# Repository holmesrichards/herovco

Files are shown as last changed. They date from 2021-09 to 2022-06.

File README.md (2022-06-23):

# Hero VCO

The Hero VCO is a 3340 based voltage controlled oscillator synth module in Kosmo format. Notable features of the Hero include:

* Triangle, ramp, pulse, and sine waveforms with separate output jacks.
* Uniform, zero-centered ±5 Vpp output amplitudes for the various wave shapes.
* Input jacks for two V/oct CVs, as well as PWM, linear FM, and exponential FM (pitch) CVs with attenuators.
* Separate initial pulse width and PWM attenuator knobs.
* Wide pulse width range.
* Switch selectable hard, soft, or no sync.
* 11 position octave switch plus fine tuning knob.
* Front panel access to trimmers for calibration of V/oct tracking, center pitch, and pulse width range limit.
* Entirely through hole construction with readily available components.

Two well known problems with the 3340 in its datasheet configuration are addressed:

* Regulated -5 V supply improves stability and suppresses pulse width frequency shift.
* Falling edge oscillations on pulse wave shape are eliminated.

But perhaps the most significant feature of the design is the link header. This may be used to connect the Hero to one or more of its sister module, the [Sidekick VCO](https://github.com/holmesrichards/sidekickvco), in a modern riff on the classic Moog 921a/921b system. The Sidekick is half the width of the Hero and lacks some of the Hero's front panel controls and inputs, but internally is essentially the same circuit as the Hero. Via the link, the Sidekicks receive summed V/oct pitch CV, linear FM CV, and pulse width CV from the Hero, based on its front panel controls and inputs. In this way a common set of control voltages is presented to the Hero and all its Sidekicks. The link also permits the Sidekicks to be hard or soft synced to the Hero. This allows easy configuration of a multi-oscillator synth voice in a relatively compact system.

The Hero design specifies and assumes the Alfa AS3340A VCO chip, an improvement to the AS3340, although the AS3340 or Curtis CEM3340 probably would work. (See build notes.)

Thanks for inspiration to several other VCOs: the [Kassutronics VCO 3340](https://kassu2000.blogspot.com/2018/06/vco-3340.html), the [LMNC 1222 Performance VCO](https://www.lookmumnocomputer.com/1222-performance-vco), and the [Thomas Henry VCO Maximus](https://www.birthofasynth.com/Thomas_Henry/Pages/VCO_Maximus-Detail.html).

## Project status

One prototype (v. 0.91) has been built and it works. There were some minor issues identified:

- L79L05 footprint does not have wide leg spacing.
- Jack footprints are round holes instead of slots.
- 330pF cap footprint is 2.5 mm pitch, should be 5 mm.
- Resistors specified for octave switch are 100k, 10k would be (arguably) better.
- No indication on silkscreen for which resistors to match.
- Some silkscreen refs obscured by pads.
- Resistors between trimmers make assembly awkward, move to other side of board.
- Slide switch footprint incorrect, requires cutting off mounting legs.

See build notes for mitigations. These issues have been corrected in the design files but the revised version has not been tested. 

## Width

10 cm.

## Current draw
33 mA +12 V, 34 mA -12 V.

## Photos

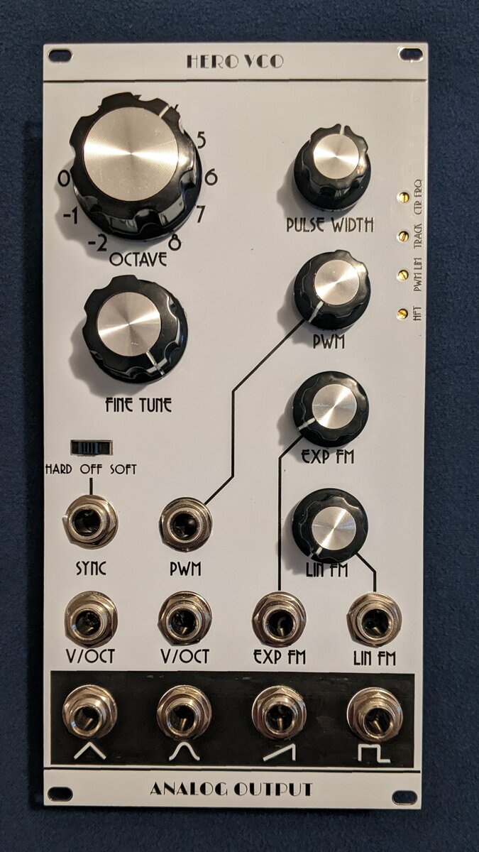
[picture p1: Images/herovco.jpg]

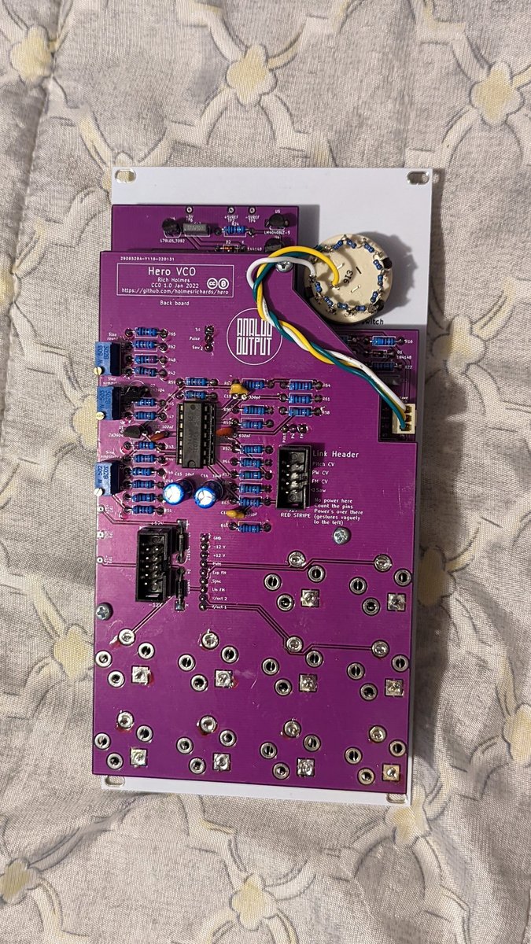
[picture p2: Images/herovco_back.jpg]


## Documentation

* [Schematic](Docs/herovco.pdf)
* PCB layout: [front](Docs/herovco_layout_front.pdf), [back](Docs/herovco_layout_back.pdf)
* [BOM](Docs/herovco_bom.md)
* [Build notes](Docs/build.md)
* [How it works](Docs/howitworks.md)
* [Blog post](https://analogoutputblog.wordpress.com/2022/06/20/hero-and-sidekick/)

## GitHub repository

* [https://github.com/holmesrichards/herovco](https://github.com/holmesrichards/herovco)

## Submodules

This repo uses submodules aoKicad and Kosmo_panel, which provide needed libaries for KiCad. To clone:

```
git clone git@github.com:holmesrichards/herovco.git
git submodule init
git submodule update
```

Alternatively do

```
git clone --recurse-submodules git@github.com:holmesrichards/herovco.git
```

Or if you download the repository as a zip file, you must also click on the "aoKicad" and "Kosmo\_panel" links on the GitHub page (they'll have "@ something" after them) and download them as separate zip files which you can unzip into this repo's aoKicad and Kosmo\_panel directories.

If desired, copy the files from aoKicad and Kosmo\_panel to wherever you prefer (your KiCad user library directory, for instance, if you have one). Then in KiCad, go into Edit Symbols and add symbol libraries 

```
aoKicad/ao_symbols
Kosmo_panel/Kosmo
```
and go into Edit Footprints and add footprint libraries 
```
aoKicad/ao_tht
Kosmo_panel/Kosmo_panel.
```

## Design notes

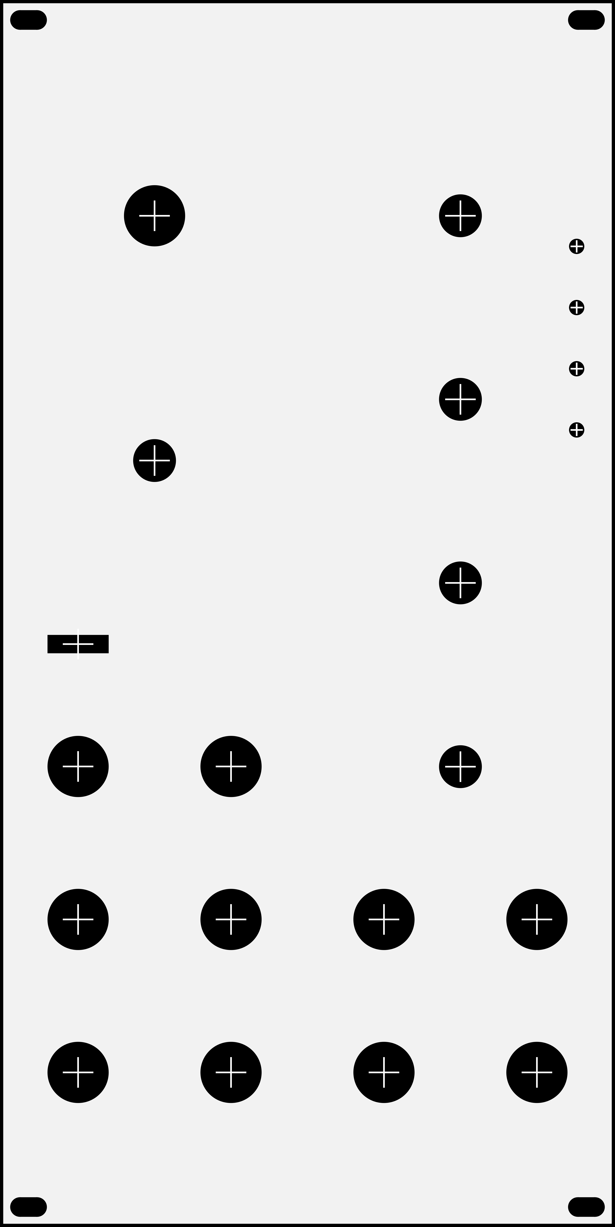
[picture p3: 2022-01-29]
Images/herovco_panel_holes.png

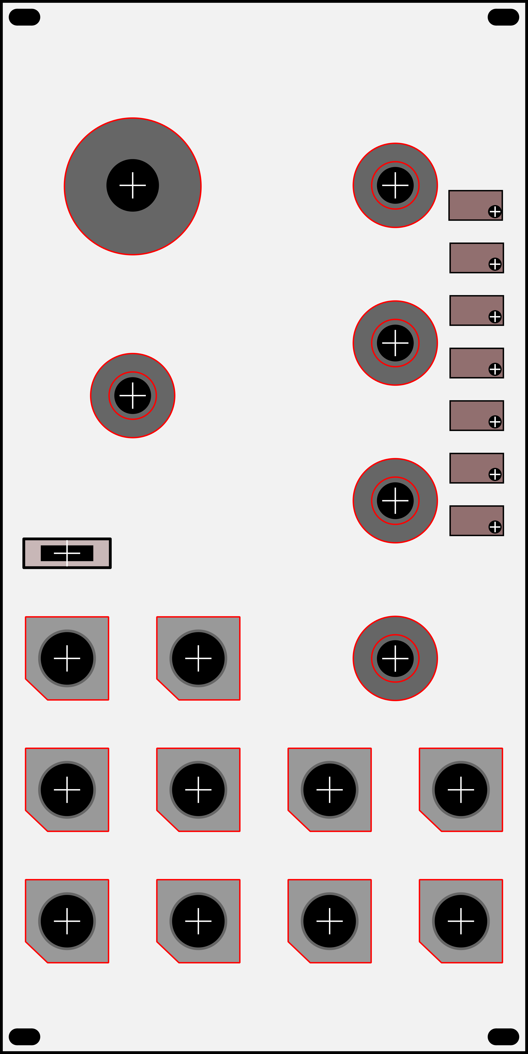
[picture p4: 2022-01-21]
Images/herovco_panel_behind.png

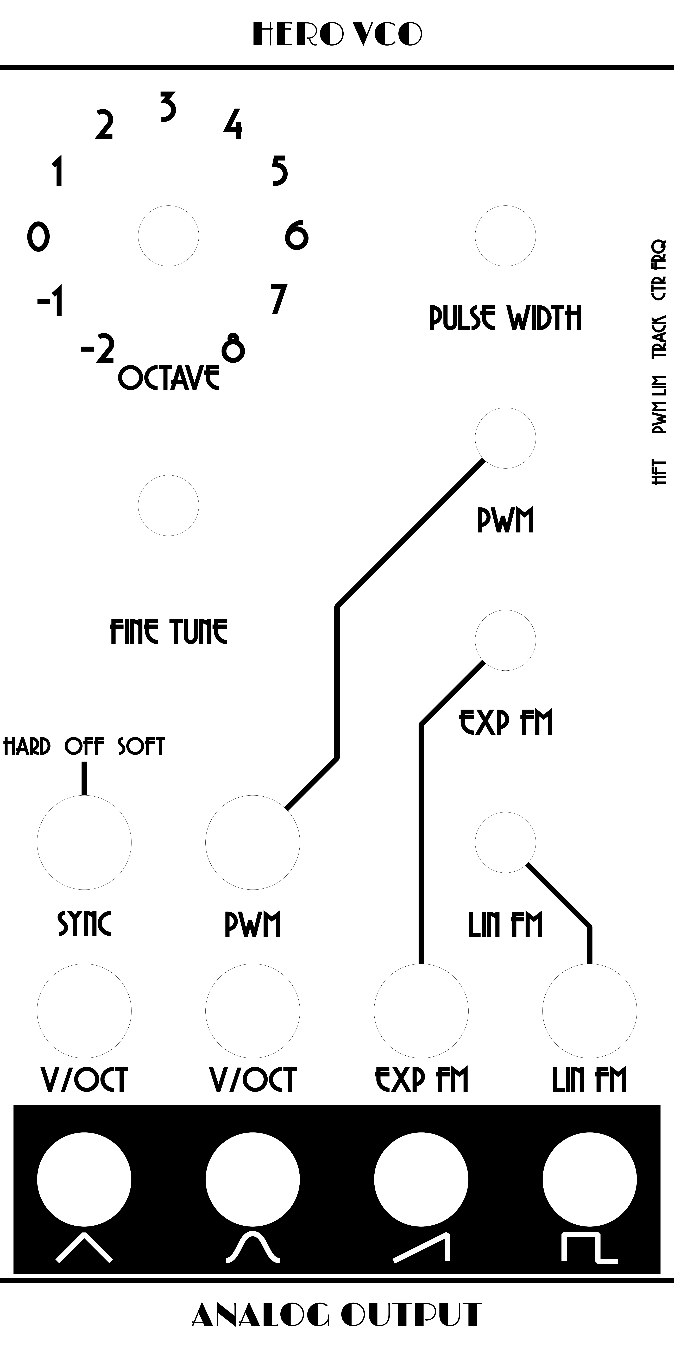
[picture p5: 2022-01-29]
Images/herovco_panel_art.png

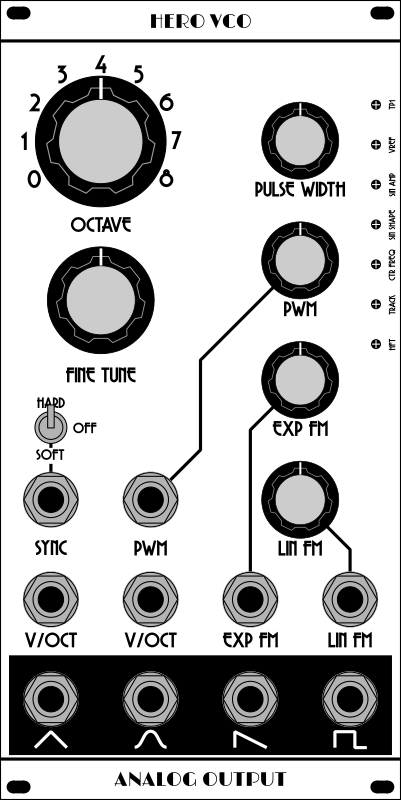
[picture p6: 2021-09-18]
Images/herovco_panel.png

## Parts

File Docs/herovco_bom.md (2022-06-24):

# herovco.kicad_sch BOM

Sun 19 Jun 2022 12:42:01 PM EDT

Generated from schematic by Eeschema 6.0.5-a6ca702e91~116~ubuntu20.04.1

**Component Count:** 133

| Refs | Qty | Component | Description | Manufacturer | Part | Vendor | SKU |
| ----- | --- | ---- | --- | ---- | ---- | ---- | ---- |
| C1, C2, C3, C4, C5, C6, C16, C17 | 8 | 100nF | Ceramic capacitor, pitch 2.5 mm |  |  | Tayda |  |
| C7, C12 | 2 | 100nF | Film capacitor, pitch 5 mm |  |  | Tayda | A-564 |
| C8, C10, C11, C13 | 4 | 10nF | Film capacitor, pitch 5 mm |  |  | Tayda | A-559 |
| C9 | 1 | 1nF | Polypropylene film capacitor |  |  | Digi-Key | FKP2G011001D00HSSD |
| C14, C15 | 2 | 10uF | Electrolytic capacitor, pitch 2.5 mm |  |  | Tayda |  |
| C18, C19 | 2 | 330pF | Ceramic capacitor, pitch 5 mm |  |  | Tayda |  |
| D1, D2 | 2 | 1N4148 | Standard switching diode, DO-35 |  |  | Tayda | A-157 |
| D3, D4 | 2 | 1N5817 | Schottky Barrier Rectifier Diode, DO-41 |  |  | Tayda | A-159 |
| J1 | 1 | Conn_01x09 | 1x9 pin header, pitch 2.54 mm |  |  |  |  |
| J2, J3 | 2 | Conn_01x03 | 1x3 pin header, pitch 2.54 mm |  |  |  |  |
| J4 | 1 | 3_pin_Molex_header | KK254 Molex header |  |  | Tayda | A-805 |
| J9 | 1 | Conn_01x09 | 1x9 pin socket, pitch 2.54 mm |  |  |  |  |
| J10, J11 | 2 | Conn_01x03 | 1x3 pin socket, pitch 2.54 mm |  |  |  |  |
| J12 | 1 | 3_pin_Molex_connector | KK254 Molex connector |  |  | Tayda | A-827 |
| J17 | 1 | Conn_02x04_Odd_Even | 2x4 shrouded pin header, pitch 2.54 mm |  |  | Tayda | A-2948 |
| J18, J19, J20, J21, J22, J24, J25, J26, J27, J28 | 10 | AudioJack2 | 1/4" audio jack, vertical |  |  | Tayda | A-1121 |
| J23 | 1 | Synth_power_2x5 | 2x5 shrouded pin header, pitch 2.54 mm |  |  | Tayda | A-2939 |
| Q1, Q2 | 2 | 2N3904 | Small Signal NPN Transistor, TO-92 |  |  | Tayda | A-111 |
| R1, R18, R19 | 3 | 1M | Resistor |  |  | Tayda |  |
| R2, R56, R57, R58 | 4 | 24k | Resistor |  |  | Tayda |  |
| R3, R16 | 2 | 5.6k | Resistor |  |  | Tayda |  |
| R4, R5, R6, R8, R10, R21, R26, R28 | 8 | 100k | Resistor |  |  | Tayda |  |
| R7 | 1 | 470k | Resistor |  |  | Tayda |  |
| R9, R12, R22, R27, R31, R44, R46, R62, R63, R64 | 10 | 10k | Resistor |  |  | Tayda |  |
| R11, R15 | 2 | 470R | Resistor |  |  | Tayda |  |
| R13 | 1 | 1.8k | Resistor |  |  | Tayda |  |
| R14 | 1 | 1.5M | Resistor |  |  | Tayda |  |
| R17, R20, R29 | 3 | 47k | Resistor |  |  | Tayda |  |
| R23, R24, R65, R66, R67 | 5 | 1k | Resistor |  |  | Tayda |  |
| R25 | 1 | 240k | Resistor |  |  | Tayda |  |
| R30, R49, R50 | 3 | 20k | Resistor |  |  | Tayda |  |
| R32, R33, R34, R35, R36, R37, R38, R39, R40, R41 | 10 | 10k 1/8W | Resistor |  |  | Tayda |  |
| R42 | 1 | 30k | Resistor |  |  | Tayda |  |
| R43, R48 | 2 | 2.2k | Resistor |  |  | Tayda |  |
| R45 | 1 | 390R | Resistor |  |  | Tayda |  |
| R47, R52, R54, R55 | 4 | 18k | Resistor |  |  | Tayda |  |
| R51 | 1 | 2k | Resistor |  |  | Tayda |  |
| R53 | 1 | 33k | Resistor |  |  | Tayda |  |
| R59, R60, R61 | 3 | 9.1k | Resistor |  |  | Tayda |  |
| RV1, RV3, RV4, RV7, RV8 | 5 | 100k | Board mount linear potentiometer |  |  | Tayda | A-1848 or A-5513 |
| RV2, RV5, RV6 | 3 | 10k | 3296W trimmer potentiometer |  |  | Tayda | A-586 |
| RV9, RV10, RV11 | 3 | 50k | 3296W trimmer potentiometer |  |  | Tayda | A-598 |
| RV12 | 1 | 5k | 3296W trimmer potentiometer |  |  | Tayda | A-597 |
| SW1 | 1 | SW_Rotary12 | rotary switch with 12 positions |  |  | Tayda | A-1893 |
| SW2 | 1 | SW_DP3T | Switch, three position, dual pole triple throw, 3 position switch, SP3T | C&K | OS203012MU5QP1‎ | Digi-Key | CKN9554-ND |
| U1, U7 | 2 | TL074 | Quad operational amplifier, DIP-14 |  |  | Tayda | A-1138 |
| U2 | 1 | TL072 | Dual operational amplifier, DIP-8 |  |  | Tayda | A-037 |
| U3 | 1 | AS3340A | VCO |  |  | CabinTech Global |  |
| U4, U5 | 2 | LM4040BIZ-5 | 5.000V Precision Micropower Shunt Voltage Reference, TO-92 |  |  | Digi-Key | LM4040BIZ-5/NOPB-ND |
| U6 | 1 | L79L05_TO92 | Negative 100mA -30V Linear Regulator, Fixed Output -5V, TO-92 |  |  | Tayda | A-4676 |
| | 6 | | Knob | | | | |
| | 1 | | 8 pin DIP socket | | | Tayda | A-001 |
| | 2 | | 14 pin DIP socket | | | Tayda | A-004 |
| | 1 | | 16 pin DIP socket | | | Tayda | A-003 |

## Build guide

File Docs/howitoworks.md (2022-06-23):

# How the Hero VCO works

## Control voltages

RV4 and U1D attenuate and buffer the linear FM control voltage. It is AC coupled by C10, then R18 converts the voltage to current for input to the 3340 chip. The buffered CV is also sent to the link header.

The octave switch voltage output is buffered by U1A. The exponential CV is attenuated by RV3. RV1 supplies an adjustable offset voltage for fine tuning. All of these together with the two V/oct CVs are summed and inverted via R4 through R8, U1B, and R10, then re-inverted by R9, R12, and U1C, all with unity gain. To make sure the octave switch and V/oct CVs remain accurately 1 V/oct the gains of both stages must be accurately unity, so the relevant input and feedback resistors must be matched. The output of U1C goes to the link header, and to summing resistor R21. RV5 attenuates the high frequency tracking voltage from the 3340, and RV6 creates an adjustable offset voltage to set the center frequency. They also go to summing resistors and from there to the 3340 CV node.

The sync input is sent via switch SW2 to either the hard or soft sync circuit, or neither. For hard sync the level is divided by R15 and R22, the pulse width is set by those in combination with C7, and D1 causes only negative going pulses to be sent. For soft sync, R17 combined with C7 establishes the pulse width. If neither is selected, C12 is connected to the soft sync pin as recommended in the 3340 datasheet.

The pulse width modulation CV is attenuated by RV8, and RV7 supplies an adjustable pulse width voltage; these are summed and inverted with suitable gains by R25, R26, R28, and U2A. R29, R30, and RV9 scale and offset the resulting voltage to correspond to the 3340's PWM range (about 0 to 4 V with 12 V supply). R27, R31, and U2B re-invert the sum to be sent to the link header.

## 3340

The 3340 connections are mostly as in the datasheet. VEE is connected directly to -5 V, rather than via a resistor to -12 V, to improve performance and eliminate the pulse width frequency shift. R1 between pins 4 and 5 eliminates ringing oscillations on the falling edge of the pulse waveform.

## ±5 V references

Two LM4040 shunt voltage references, U4 and U5, are used with current limiting resistors R23 and R24 to create accurate ±5 V references, used by the fine tune control, center frequency trimmer, and octave switch.

## -5 V regulator

U6 is a voltage regulator to supply negative power to the 3340. D2 and C13 are per the L79L05 datasheet.

## Octave switch

Matched 10k resistors form a precision voltage divider between ±5 V whose output is +5, +4, +3, ... -4, -5 V. 

## Output conditioning

The 3340's waveform outputs are about 0 to 10.5 V for pulse, 0 to 8 V for ramp/saw, and 0 to 4 V for triangle. The triangle waveform is rescaled and offset to ±5 V by R56, R59, R62, and U7C. R56 and R59 divide +12 V down to the desired offset and the ratio of R62 to these resistors sets the gain. R65 limits current to the waveform output jack. 

The same rescaling and offset circuit is used on the ramp and pulse waveforms as well, after a voltage divider (R52 and R54 for ramp, R53 and R55 for pulse) scales these outputs down to 0 to 4 V. R53 and R55 also serve as a 51k pulldown as called for in the AS3340 datasheet.

Using the +12 V rail for the offset means it is sensitive to power supply fluctuations, but this is not likely to be a concern.

## Sine shaping

The sine shaping circuit is based on a differential transistor pair, Q1 and Q2. This is a standard tri to sine design. The amount of rounding depends on the input signal level so attenuator RV10 gives control over that. RV11 adjusts the balance between the two transistors' bias to control the symmetry of the rounding. U7D with R49 and R50 is a differential current amplifier, turning the difference in the collector currents into an output voltage. R51 and RV12 attenuate the output down to ±5 V.

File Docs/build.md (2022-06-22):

# Hero VCO build notes

## v0.91 issues

The first PCB run (v0.91) had some minor issues, easily worked around:

- L79L05 footprint does not have wide leg spacing. The irony is that of the five TO-92 devices in the VCO, this was for me the only one whose legs were wide spread as supplied. They had to be bent back inward. (And the legs on the other four I bent outward.)
- 330pF cap footprint is 2.5 mm pitch. The caps I had were 5 mm pitch. Again, I bent the legs inward.
- Slide switch footprint is incorrect. Electrically it is fine but the two holes for the mounting pins are placed wrong. I just cut the mounting pins off the switch and relied on the terminals to hold it in place.
- Resistors R2, R19, R20, and R30, located between the trimmer footprints on the front board on the same side as the other non-pot components, make it a little awkward to solder those trimmers later. You can move those resistors to the other side of the PCB to solve that. (In later versions the silkscreen shows these on the pots side of the board.)

## Which chip

The design specifies and assumes the Alfa AS3340A VCO chip, an improvement to the AS3340, although the AS3340 or Curtis CEM3340 probably would work. I have not tested either extensively. The CEM datasheet says the pulse output should have a 10k pulldown, versus 51k for the AS3340(A), though reportedly anything in that range works acceptably for either (see Sam Battle's LMNC 1222 schematic). If using CEM and you want to stick to the datasheet you could try changing R53 from 33k to 6.2k and R55 from 18k to 3.6k.

## Resistor matching

For proper V/oct tuning, certain groups of resistors need to be matched to one another to high precision. You can buy 0.1% precision resistors, but it is much cheaper to buy 100 or so 1% resistors and then measure them, setting aside ones that match at the 0.1% level. The actual value of the resistance is not critical, only that it be the same for resistors in each group. Different groups do not need to match each other.

Resistor groups to be matched are:

* Summing and feedback resistors in pitch CV input stage: R4, R5, R6, and R10 (100k). Note the resistors after the fine tune and CV in knobs do not need to be matched.
* Summing and feedback resistors in inverter stage: R9, R12 (10k).
* Octave switch resistors: R32 through R41 (10k).

*It would not hurt to make a note of the resistance values for each group.* You will want to know this if you ever need to replace one of these resistors.

## Octave switch

Resistors R32 through R41 are not mounted on the PCB; they are soldered directly to the octave switch: R41 from pin 1 to pin 2, R40 from pin 2 to pin 3, and so on up through R32 from pin 10 to pin 11. (Nothing is connected to pin 12.) These resistors are specified as 1/8 W metal film, solely because they fit nicely between the switch pins. You can use 1/4 watt resistors if that is what you have. They're just more awkward to place.

Three wires are connected to a Molex connector, to attach to header J4 on the circuit board. The wire connecting to the header pin marked +5V connects to rotary switch pin 11. The wire to header pin -5V connects to pin 1. The wire to header pin Octave connects to the center pin.

## Mechanical assembly

As usual, components that are mounted to or aligned with holes in the front panel should be put in place on the PCB without soldering, then the panel should be put on, then the parts should be soldered.

With the parts I used, the combined heights of the pin headers and sockets was going to be a couple mm short of the spacing between the PCBs. To reduce that discrepancy I put a couple of washers on each pot shaft underneath the front panel. There still is a gap between the pin header and socket housings but it's smaller and they make good electrical contact.

### Slide switch daughterboard
With those washers in place I did the following:

* I soldered the slide switch to its daughterboard. See note above about erroneous footprint in version v0.91. Switch goes on the side with the footprint on the silkscreen.
* With the daughterboard switch side down, I put a piece of solid wire (resistor leg cutoffs) in each of the four corner holes and soldered them. I clipped them off on the switch side.
* I fed the four wires through the holes in the PCB, making sure the labels on the daughterboard matched those on the PCB.
* I put the front panel on, securing it to the pots with nuts.
* I turned the assembly panel side down, propping up the ends off the work surface, and made sure the switch actuator was going through its hole with the switch housing flush against the back of the panel.
* I soldered the four wires to the PCB and clipped off the excess.

Again, do that with the washers in place on the pot shafts!

## Calibration
The main calibration is the usual procedure with 3340 based oscillators:

* With the octave swich in position 3 adjust the Center freq trimmer to get a fairly low frequency (100 Hz or so)
* Use a calibrated V/oct source such as a CV keyboard or MIDI/CV module to send 0 V and 2 V alternately to the V/oct input. Adjust the Tracking trimmer until the frequency ratio at these two CV values equals 2.000 ± 0.002.
* Turn the octave switch up to position 6. Again alternating 0 V and 2 V on the V/oct input, adjust the Hi freq track trimmer until the frequency ratio at these two CV values equals 2.000 ± 0.002.
* Repeat the last two steps if necessary to get the tracking as accurate as you can.
* Re-adjust the center frequency trimmer to your liking. I set it so with no CV inputs, the octave switch on 4, and the fine tuning knob centered, the pitch was C4 (262 Hz).

(I did the calibration using my new MI Module Tester and it made it so easy it was ridiculous!)

There are still four more trimmers! One is for the PWM upper limit. With no PWM CV, adjust it so when you turn the Pulse width knob up the pulse waveform either never gets so wide it stops, or gets just barely to the stopping point, as you prefer.

The other three trimmers are for the sine waveform. Put the sine waveform on a scope and adjust Sine symmetry to make the top and bottom of the waveform the same; adjust Sine round to make it a good sine shape. Once you're happy with those, adjust Sine amplitude to make the waveform 10 V peak to peak.

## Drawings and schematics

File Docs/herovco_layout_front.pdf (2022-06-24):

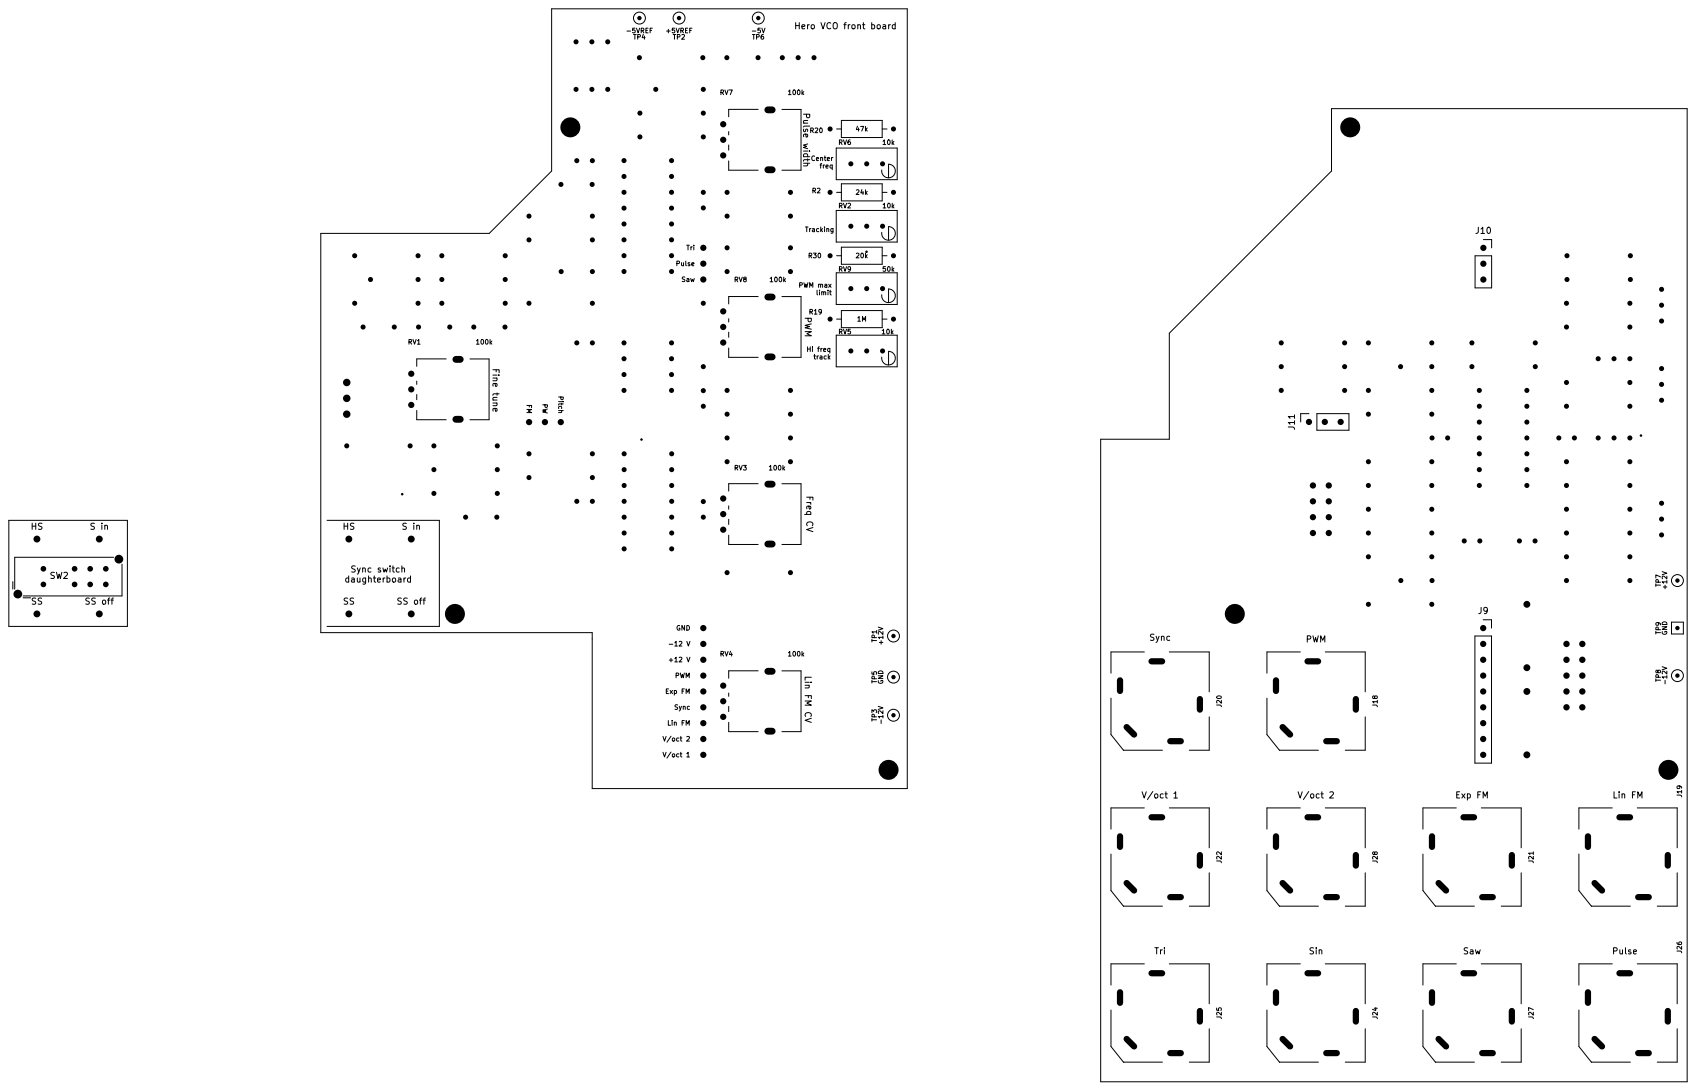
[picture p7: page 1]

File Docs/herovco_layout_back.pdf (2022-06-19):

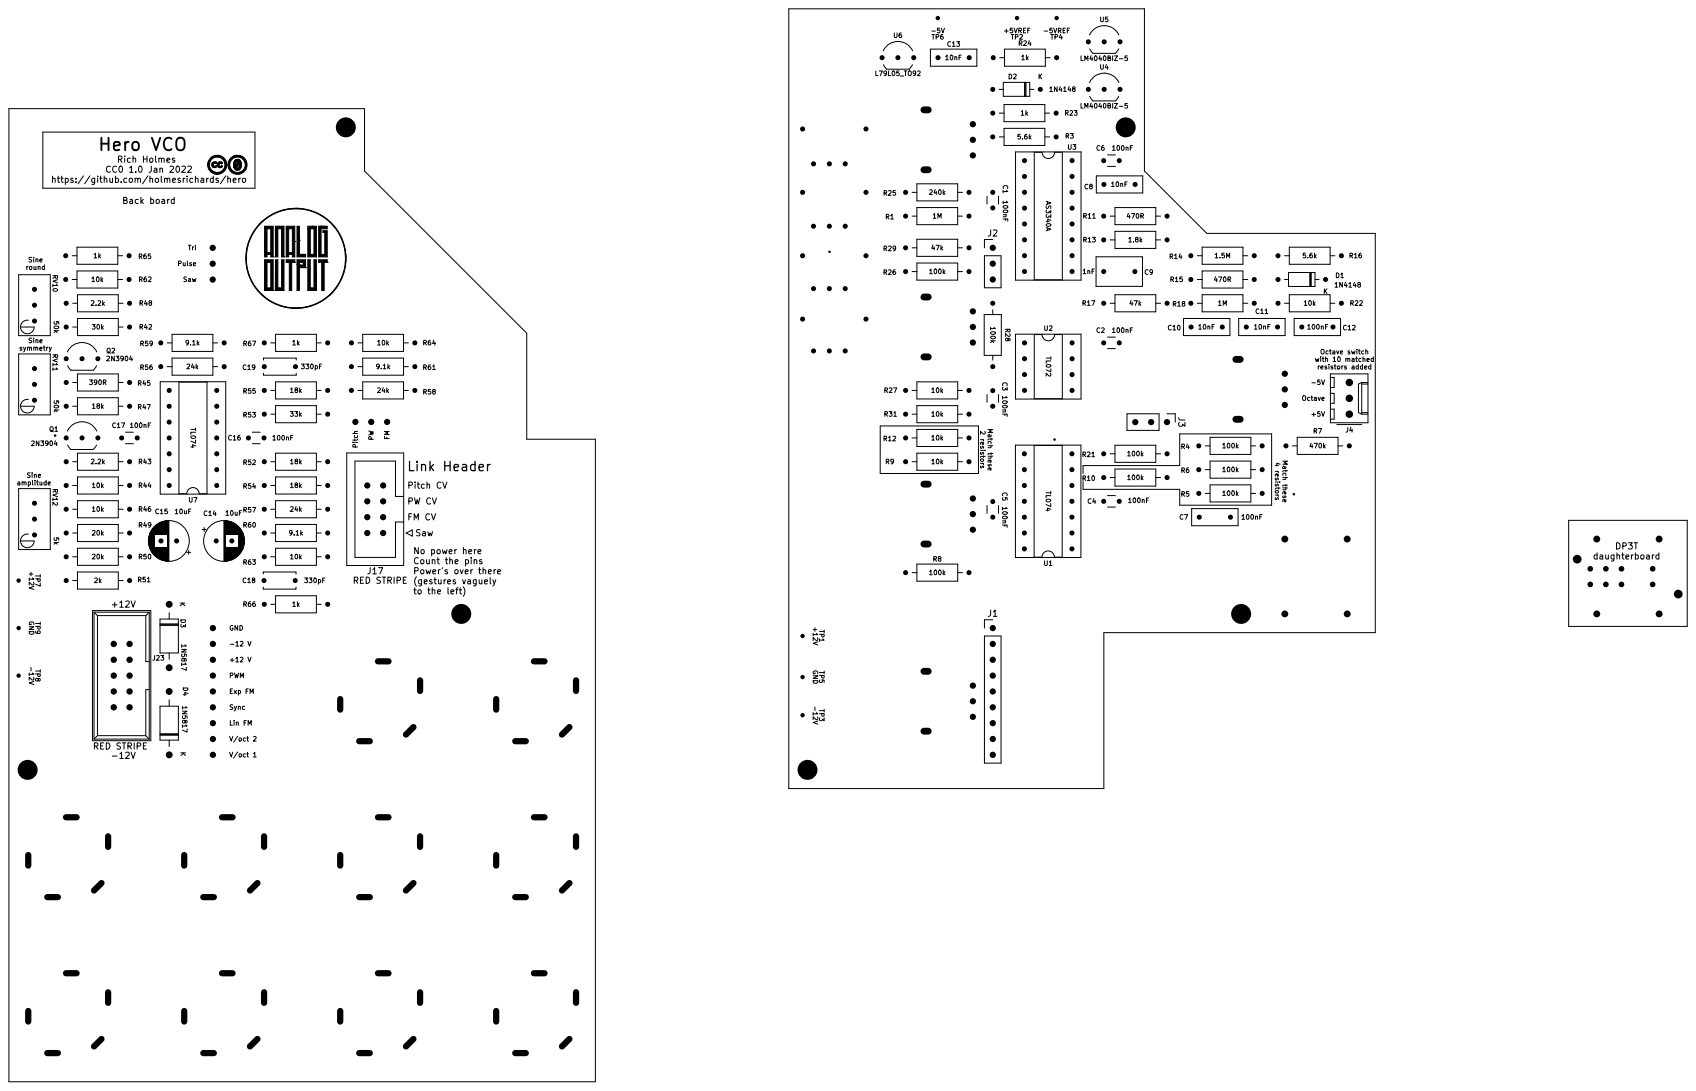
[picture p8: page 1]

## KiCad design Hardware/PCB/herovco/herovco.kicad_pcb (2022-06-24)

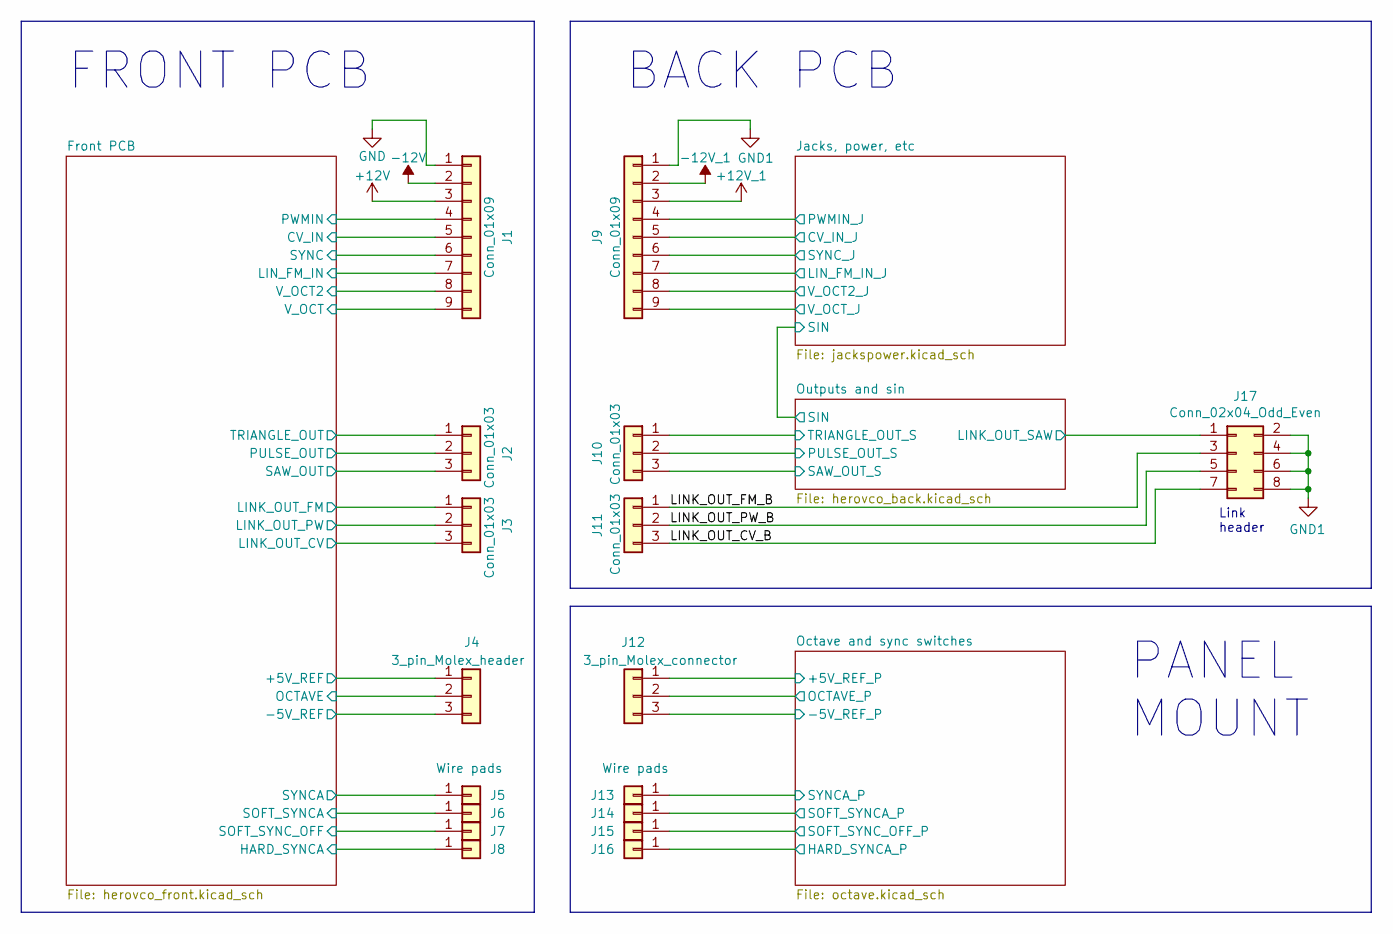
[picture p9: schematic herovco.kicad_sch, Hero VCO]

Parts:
J1: Conn_01x09; PinHeader_1x09_P2.54mm_Vertical
J2, J3: Conn_01x03; PinHeader_1x03_P2.54mm_Vertical
J4: 3_pin_Molex_header; Molex_KK-254_AE-6410-03A_1x03_P2.54mm_Vertical
J5, J13: Wire pads; SolderWire-0.5sqmm_1x01_D0.9mm_OD2.1mm
J6, J7, J8, J14, J15, J16: Conn_01x01; SolderWire-round_1x01_D0.9mm_OD2.1mm
J9: Conn_01x09; PinSocket_1x09_P2.54mm_Vertical
J10, J11: Conn_01x03; PinSocket_1x03_P2.54mm_Vertical
J12: 3_pin_Molex_connector; Molex_KK-254_AE-6410-03A_1x03_P2.54mm_Vertical
J17: Conn_02x04_Odd_Even; IDC-Header_2x04_P2.54mm_Vertical

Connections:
+12V: J1.3; also elsewhere on the board
+12V_1: J9.3; also elsewhere on the board
-12V: J1.2; also elsewhere on the board
-12V_1: J9.2; also elsewhere on the board
/Front PCB/+5V_REF: J4.1; also elsewhere on the board
/Front PCB/-5V_REF: J4.3; also elsewhere on the board
/Front PCB/CV_IN: J1.5; also elsewhere on the board
/Front PCB/CV_SUM: J3.3; also elsewhere on the board
/Front PCB/HARD_SYNCA: J8.1; also elsewhere on the board
/Front PCB/LINK_OUT_FM: J3.1; also elsewhere on the board
/Front PCB/LINK_OUT_PW: J3.2; also elsewhere on the board
/Front PCB/LIN_FM_IN: J1.7; also elsewhere on the board
/Front PCB/OCTAVE: J4.2; also elsewhere on the board
/Front PCB/PULSE_OUT: J2.2; also elsewhere on the board
/Front PCB/PWMIN: J1.4; also elsewhere on the board
/Front PCB/SAW_OUT: J2.3; also elsewhere on the board
/Front PCB/SOFT_SYNCA: J6.1; also elsewhere on the board
/Front PCB/SOFT_SYNC_OFF: J7.1; also elsewhere on the board
/Front PCB/SYNC: J1.6; also elsewhere on the board
/Front PCB/SYNCA: J5.1; also elsewhere on the board
/Front PCB/TRIANGLE_OUT: J2.1; also elsewhere on the board
/Front PCB/V_OCT: J1.9; also elsewhere on the board
/Front PCB/V_OCT2: J1.8; also elsewhere on the board
/Jacks, power, etc/CV_IN_J: J9.5; also elsewhere on the board
/Jacks, power, etc/LIN_FM_IN_J: J9.7; also elsewhere on the board
/Jacks, power, etc/PWMIN_J: J9.4; also elsewhere on the board
/Jacks, power, etc/SYNC_J: J9.6; also elsewhere on the board
/Jacks, power, etc/V_OCT2_J: J9.8; also elsewhere on the board
/Jacks, power, etc/V_OCT_J: J9.9; also elsewhere on the board
/LINK_OUT_CV_B: J11.3, J17.7
/LINK_OUT_FM_B: J11.1, J17.3
/LINK_OUT_PW_B: J11.2, J17.5
/Octave and sync switches/HARD_SYNCA_P: J16.1; also elsewhere on the board
/Octave and sync switches/SOFT_SYNCA_P: J14.1; also elsewhere on the board
/Octave and sync switches/SOFT_SYNC_OFF_P: J15.1; also elsewhere on the board
/Octave and sync switches/SYNCA_P: J13.1; also elsewhere on the board
/Outputs and sin/LINK_OUT_SAW: J17.1; also elsewhere on the board
/Outputs and sin/PULSE_OUT_S: J10.2; also elsewhere on the board
/Outputs and sin/SAW_OUT_S: J10.3; also elsewhere on the board
/Outputs and sin/TRIANGLE_OUT_S: J10.1; also elsewhere on the board
GND: J1.1; also elsewhere on the board
GND1: J9.1, J17.2, J17.4, J17.6, J17.8; also elsewhere on the board

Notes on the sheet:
FRONT PCB
PANEL MOUNT
Link header
BACK PCB

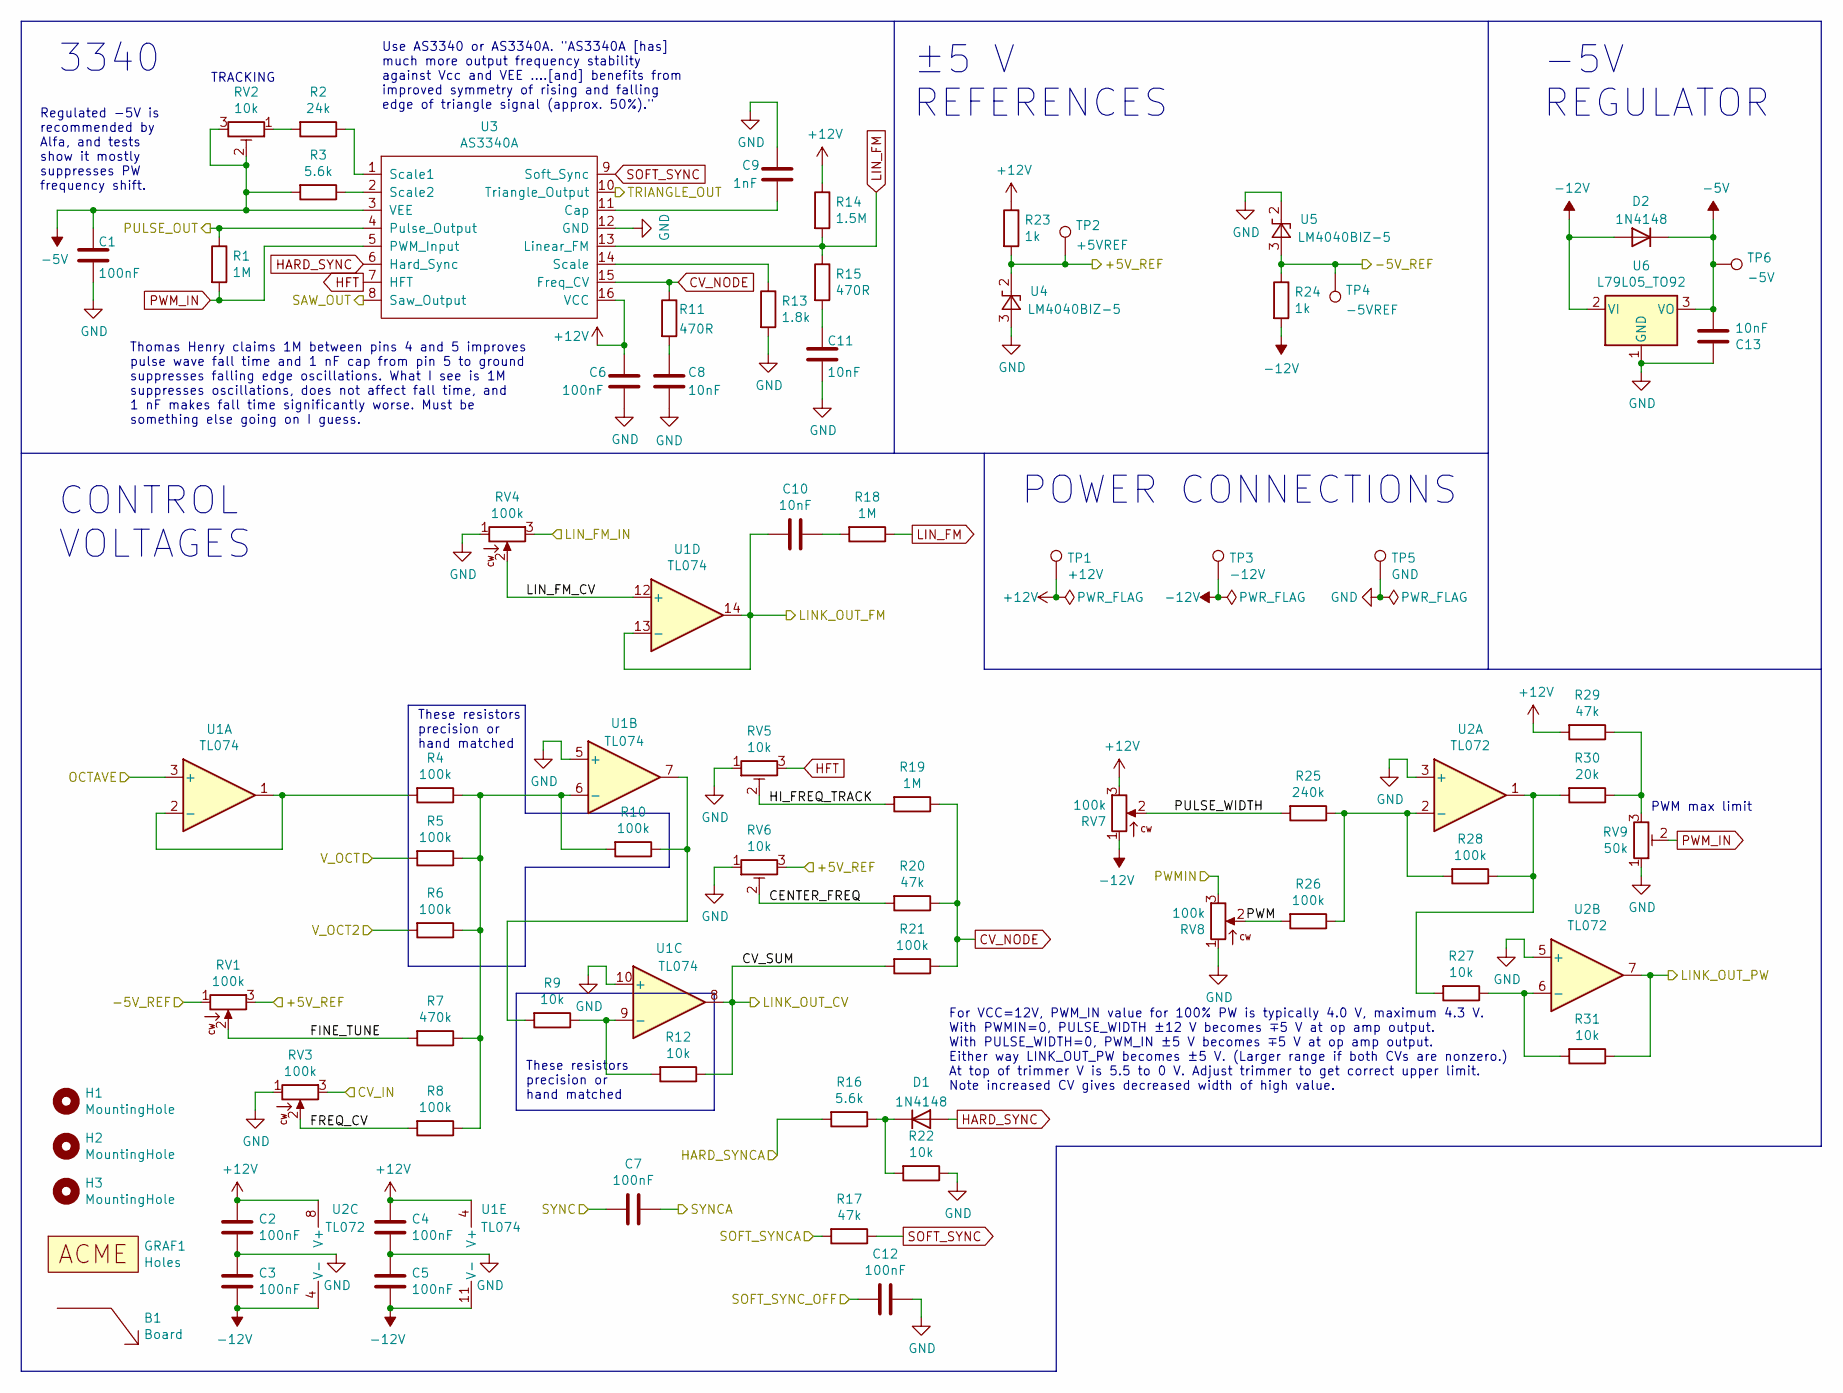
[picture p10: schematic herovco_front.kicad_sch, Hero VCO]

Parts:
B1: Board; Board_Marker
C1, C2, C3, C4, C5, C6: 100nF; C_Disc_D3.0mm_W1.6mm_P2.50mm
C7, C12: 100nF; C_Rect_L7.2mm_W2.5mm_P5.00mm_FKS2_FKP2_MKS2_MKP2
C8, C10, C11, C13: 10nF; C_Rect_L7.2mm_W2.5mm_P5.00mm_FKS2_FKP2_MKS2_MKP2
C9: 1nF; C_Rect_L7.2mm_W4.5mm_P5.00mm_FKS2_FKP2_MKS2_MKP2
D1, D2: 1N4148; D_DO-35_SOD27_P7.62mm_Horizontal
GRAF1: Holes; herovco_panel_behind
H1, H2, H3: MountingHole; MountingHole_3.2mm_M3
R1, R18, R19: 1M; R_Axial_DIN0207_L6.3mm_D2.5mm_P10.16mm_Horizontal
R2: 24k; R_Axial_DIN0207_L6.3mm_D2.5mm_P10.16mm_Horizontal
R3, R16: 5.6k; R_Axial_DIN0207_L6.3mm_D2.5mm_P10.16mm_Horizontal
R4, R5, R6, R8, R10, R21, R26, R28: 100k; R_Axial_DIN0207_L6.3mm_D2.5mm_P10.16mm_Horizontal
R7: 470k; R_Axial_DIN0207_L6.3mm_D2.5mm_P10.16mm_Horizontal
R9, R12, R22, R27, R31: 10k; R_Axial_DIN0207_L6.3mm_D2.5mm_P10.16mm_Horizontal
R11, R15: 470R; R_Axial_DIN0207_L6.3mm_D2.5mm_P10.16mm_Horizontal
R13: 1.8k; R_Axial_DIN0207_L6.3mm_D2.5mm_P10.16mm_Horizontal
R14: 1.5M; R_Axial_DIN0207_L6.3mm_D2.5mm_P10.16mm_Horizontal
R17, R20, R29: 47k; R_Axial_DIN0207_L6.3mm_D2.5mm_P10.16mm_Horizontal
R23, R24: 1k; R_Axial_DIN0207_L6.3mm_D2.5mm_P10.16mm_Horizontal
R25: 240k; R_Axial_DIN0207_L6.3mm_D2.5mm_P10.16mm_Horizontal
R30: 20k; R_Axial_DIN0207_L6.3mm_D2.5mm_P10.16mm_Horizontal
RV1, RV3, RV4, RV7, RV8: 100k; Potentiometer_Alpha_RD901F-40-00D_Single_Vertical_centered
RV2, RV5, RV6: 10k; Potentiometer_Bourns_3296W_Vertical_screw_centered
RV9: 50k; Potentiometer_Bourns_3296W_Vertical_screw_centered
TP1: +12V; TestPoint_THTPad_D1.5mm_Drill0.7mm
TP2: +5VREF; TestPoint_THTPad_D1.5mm_Drill0.7mm
TP3: -12V; TestPoint_THTPad_D1.5mm_Drill0.7mm
TP4: -5VREF; TestPoint_THTPad_D1.5mm_Drill0.7mm
TP5: GND; TestPoint_THTPad_D1.5mm_Drill0.7mm
TP6: -5V; TestPoint_THTPad_D1.5mm_Drill0.7mm
U1: TL074; DIP-14_W7.62mm_Socket_LongPads
U2: TL072; DIP-8_W7.62mm_Socket_LongPads
U3: AS3340A; DIP-16_W7.62mm_Socket_LongPads
U4, U5: LM4040BIZ-5; TO-92_Inline_Wide
U6: L79L05_TO92; TO-92_Inline_Wide

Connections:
+12V: C2.1, C4.1, C6.1, R14.1, R23.1, R29.2, RV7.3, TP1.1, U1.4 (V+), U2.8 (V+), U3.16 (VCC); also elsewhere on the board
-5V: C1.1, C13.2, D2.1 (K), R3.2, RV2.2, RV2.3, TP6.1, U3.3 (VEE), U6.3 (VO)
-12V: C3.2, C5.2, D2.2 (A), R24.2, RV7.1, TP3.1, U1.11 (V-), U2.4 (V-), U6.2 (VI); also elsewhere on the board
/Front PCB/+5V_REF: R23.2, RV1.3, RV6.3, TP2.1, U4.2 (K); also elsewhere on the board
/Front PCB/-5V_REF: R24.1, RV1.1, TP4.1, U5.3 (A); also elsewhere on the board
/Front PCB/CENTER_FREQ: R20.2, RV6.2
/Front PCB/CV_IN: RV3.3; also elsewhere on the board
/Front PCB/CV_SUM: R12.1, R21.2, U1.8; also elsewhere on the board
/Front PCB/FINE_TUNE: R7.2, RV1.2
/Front PCB/FREQ_CV: R8.2, RV3.2
/Front PCB/HARD_SYNCA: R16.2; also elsewhere on the board
/Front PCB/HI_FREQ_TRACK: R19.2, RV5.2
/Front PCB/LINK_OUT_FM: C10.2, U1.13 (-), U1.14; also elsewhere on the board
/Front PCB/LINK_OUT_PW: R31.1, U2.7; also elsewhere on the board
/Front PCB/LIN_FM_CV: RV4.2, U1.12 (+)
/Front PCB/LIN_FM_IN: RV4.3; also elsewhere on the board
/Front PCB/OCTAVE: U1.3 (+); also elsewhere on the board
/Front PCB/PULSE_OUT: R1.1, U3.4 (Pulse_Output); also elsewhere on the board
/Front PCB/PULSE_WIDTH: R25.2, RV7.2
/Front PCB/PWM: R26.2, RV8.2
/Front PCB/PWMIN: RV8.3; also elsewhere on the board
/Front PCB/SAW_OUT: U3.8 (Saw_Output); also elsewhere on the board
/Front PCB/SOFT_SYNCA: R17.2; also elsewhere on the board
/Front PCB/SOFT_SYNC_OFF: C12.2; also elsewhere on the board
/Front PCB/SYNC: C7.2; also elsewhere on the board
/Front PCB/SYNCA: C7.1; also elsewhere on the board
/Front PCB/TRIANGLE_OUT: U3.10 (Triangle_Output); also elsewhere on the board
/Front PCB/V_OCT: R5.2; also elsewhere on the board
/Front PCB/V_OCT2: R6.2; also elsewhere on the board
CV_NODE: R11.1, R19.1, R20.1, R21.1, U3.15 (Freq_CV)
GND: C1.2, C2.2, C3.1, C4.2, C5.1, C6.2, C8.2, C9.1, C11.2, C12.1, C13.1, R13.2, R22.1, RV3.1, RV4.1, RV5.1, RV6.1, RV8.1, RV9.1, TP5.1, U1.5 (+), U1.10 (+), U2.3 (+), U2.5 (+), U3.12 (GND), U4.3 (A), U5.2 (K), U6.1 (GND); also elsewhere on the board
HARD_SYNC: D1.2 (A), U3.6 (Hard_Sync)
HFT: RV5.3, U3.7 (HFT)
LIN_FM: R14.2, R15.1, R18.1, U3.13 (Linear_FM)
unnamed: C8.1, R11.2
unnamed: C9.2, U3.11 (Cap)
unnamed: C10.1, R18.2
unnamed: C11.1, R15.2
unnamed: D1.1 (K), R16.1, R22.2
unnamed: R2.1, U3.1 (Scale1)
unnamed: R2.2, RV2.1
unnamed: R3.1, U3.2 (Scale2)
unnamed: R4.2, U1.1, U1.2 (-)
unnamed: R9.2, R10.1, U1.7
unnamed: R4.1, R5.1, R6.1, R7.1, R8.1, R10.2, U1.6 (-)
unnamed: R9.1, R12.2, U1.9 (-)
unnamed: R13.1, U3.14 (Scale)
unnamed: R25.1, R26.1, R28.2, U2.2 (-)
unnamed: R27.1, R31.2, U2.6 (-)
unnamed: R27.2, R28.1, R30.2, U2.1
unnamed: R29.1, R30.1, RV9.3
PWM_IN: R1.2, RV9.2, U3.5 (PWM_Input)
SOFT_SYNC: R17.1, U3.9 (Soft_Sync)

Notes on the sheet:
3340
±5 V REFERENCES
TRACKING
For VCC=12V, PWM_IN value for 100% PW is typically 4.0 V, maximum 4.3 V. With PWMIN=0, PULSE_WIDTH ±12 V becomes ∓5 V at op amp output. With PULSE_WIDTH=0, PWM_IN ±5 V becomes ∓5 V at op amp output. Either way LINK_OUT_PW becomes ±5 V. (Larger range if both CVs are nonzero.) At top of trimmer V is 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
Use AS3340 or AS3340A. "AS3340A [has] much more output frequency stability against Vcc and VEE ....[and] benefits from improved symmetry of rising and falling edge of triangle signal (approx. 50%)."
-5V REGULATOR
These resistors precision or hand matched
PWM max limit
CONTROL VOLTAGES
Thomas Henry claims 1M between pins 4 and 5 improves pulse wave fall time and 1 nF cap from pin 5 to ground suppresses falling edge oscillations. What I see is 1M suppresses oscillations, does not affect fall time, and 1 nF makes fall time significantly worse. Must be something else going on I gues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
POWER CONNECTIONS
Regulated -5V is recommended by Alfa, and tests show it mostly suppresses PW frequency shift.

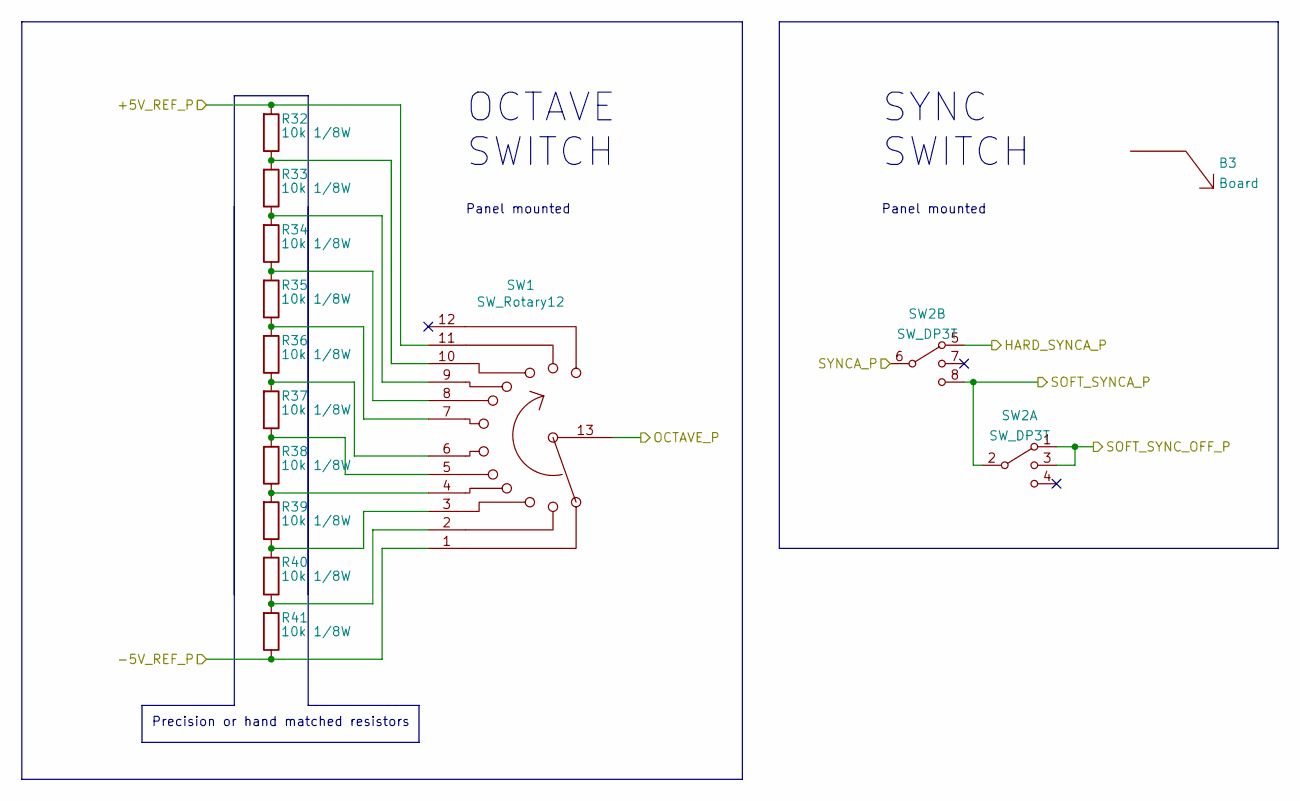
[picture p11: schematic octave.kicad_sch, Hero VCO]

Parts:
B3: Board; Board_Marker
R32, R33, R34, R35, R36, R37, R38, R39, R40, R41: 10k 1/8W; R_Axial_DIN0207_L6.3mm_D2.5mm_P10.16mm_Horizontal
SW1: SW_Rotary12; Rotary_Switch
SW2: SW_DP3T; SW_CK_OS203012MU5QP1_DP3T; Part OS203012MU5QP1‎

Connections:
/Octave and sync switches/HARD_SYNCA_P: SW2.5; also elsewhere on the board
/Octave and sync switches/SOFT_SYNCA_P: SW2.2, SW2.8; also elsewhere on the board
/Octave and sync switches/SOFT_SYNC_OFF_P: SW2.1, SW2.3; also elsewhere on the board
/Octave and sync switches/SYNCA_P: SW2.6; also elsewhere on the board
unnamed: R32.1, R33.2, SW1.10
unnamed: R32.2, SW1.11
unnamed: R33.1, R34.2, SW1.9
unnamed: R34.1, R35.2, SW1.8
unnamed: R35.1, R36.2, SW1.7
unnamed: R36.1, R37.2, SW1.6
unnamed: R37.1, R38.2, SW1.5
unnamed: R38.1, R39.2, SW1.4
unnamed: R39.1, R40.2, SW1.3
unnamed: R40.1, R41.2, SW1.2
unnamed: R41.1, SW1.1

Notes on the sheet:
Panel mounted
SYNC SWITCH
OCTAVE SWITCH
Precision or hand matched resistors

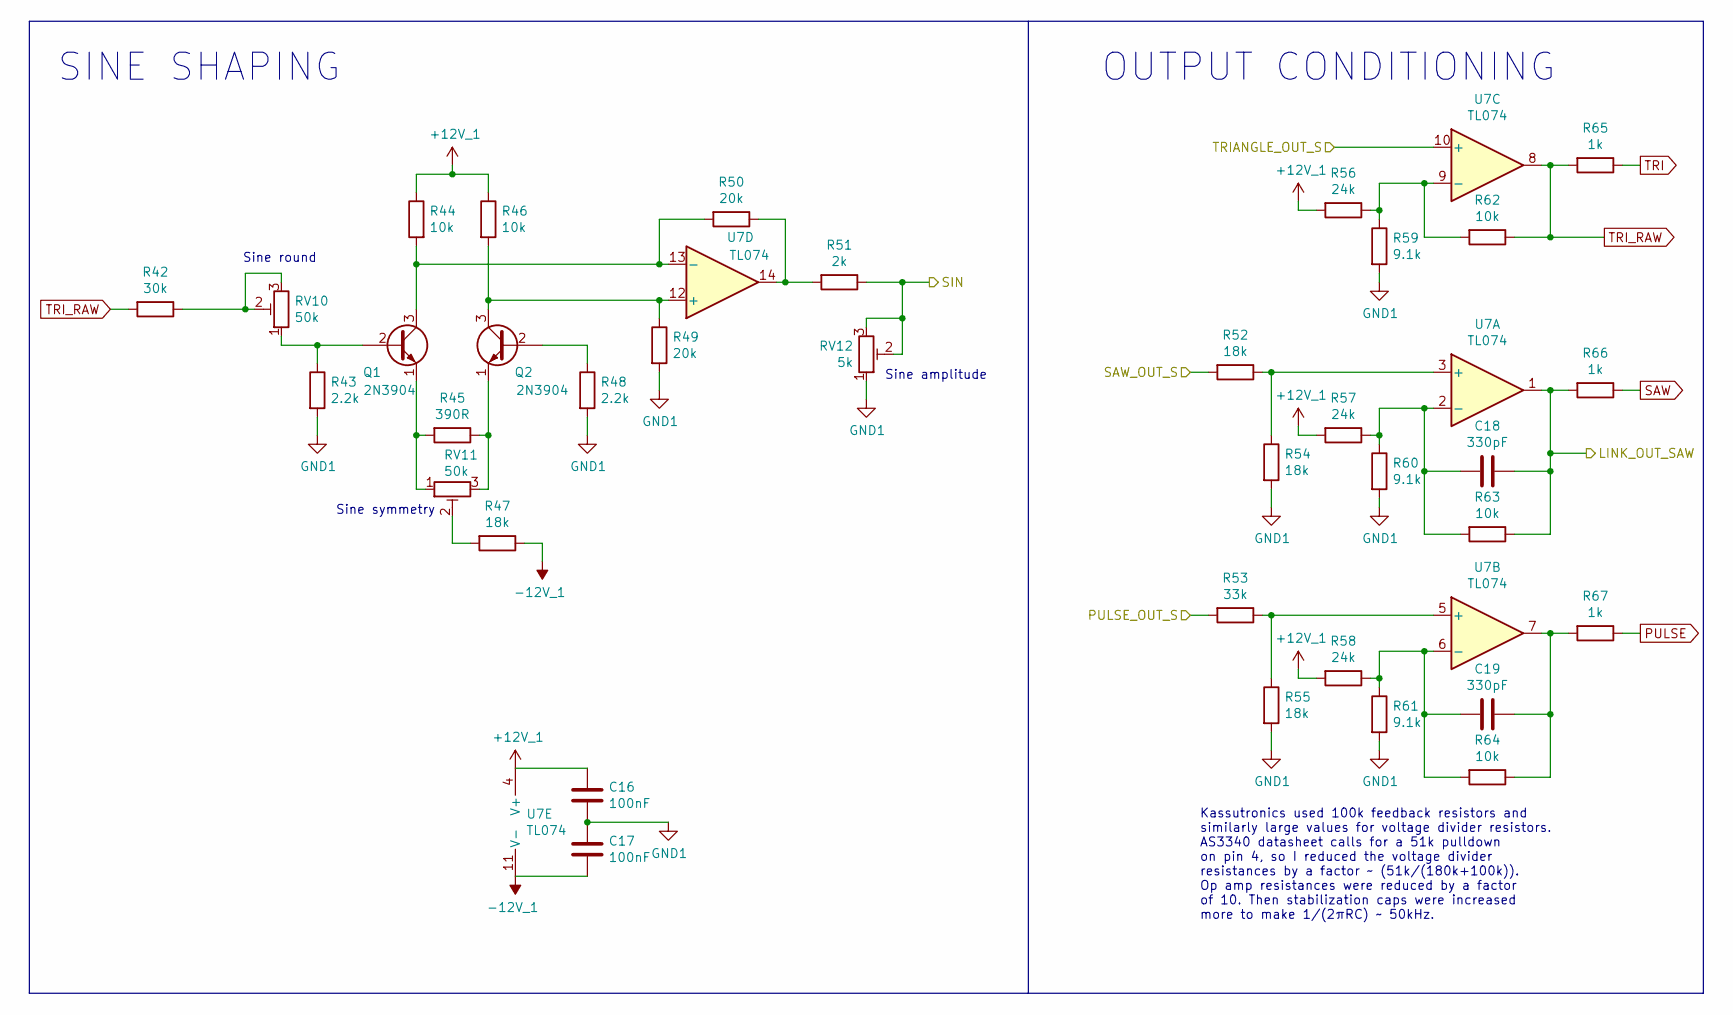
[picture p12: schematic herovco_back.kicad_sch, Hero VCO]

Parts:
C16, C17: 100nF; C_Disc_D3.0mm_W1.6mm_P2.50mm
C18, C19: 330pF; C_Disc_D5.0mm_W2.5mm_P5.00mm
Q1, Q2: 2N3904; TO-92_Inline_Wide
R42: 30k; R_Axial_DIN0207_L6.3mm_D2.5mm_P10.16mm_Horizontal
R43, R48: 2.2k; R_Axial_DIN0207_L6.3mm_D2.5mm_P10.16mm_Horizontal
R44, R46, R62, R63, R64: 10k; R_Axial_DIN0207_L6.3mm_D2.5mm_P10.16mm_Horizontal
R45: 390R; R_Axial_DIN0207_L6.3mm_D2.5mm_P10.16mm_Horizontal
R47, R52, R54, R55: 18k; R_Axial_DIN0207_L6.3mm_D2.5mm_P10.16mm_Horizontal
R49, R50: 20k; R_Axial_DIN0207_L6.3mm_D2.5mm_P10.16mm_Horizontal
R51: 2k; R_Axial_DIN0207_L6.3mm_D2.5mm_P10.16mm_Horizontal
R53: 33k; R_Axial_DIN0207_L6.3mm_D2.5mm_P10.16mm_Horizontal
R56, R57, R58: 24k; R_Axial_DIN0207_L6.3mm_D2.5mm_P10.16mm_Horizontal
R59, R60, R61: 9.1k; R_Axial_DIN0207_L6.3mm_D2.5mm_P10.16mm_Horizontal
R65, R66, R67: 1k; R_Axial_DIN0207_L6.3mm_D2.5mm_P10.16mm_Horizontal
RV10, RV11: 50k; Potentiometer_Bourns_3296W_Vertical_screw_centered
RV12: 5k; Potentiometer_Bourns_3296W_Vertical_screw_centered
U7: TL074; DIP-14_W7.62mm_Socket_LongPads

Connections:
+12V_1: C16.1, R44.1, R46.1, R56.2, R57.2, R58.2, U7.4 (V+); also elsewhere on the board
-12V_1: C17.2, R47.1, U7.11 (V-); also elsewhere on the board
/Jacks, power, etc/SIN: R51.1, RV12.2, RV12.3; also elsewhere on the board
/Outputs and sin/LINK_OUT_SAW: C18.1, R63.1, R66.2, U7.1; also elsewhere on the board
/Outputs and sin/PULSE_OUT_S: R53.2; also elsewhere on the board
/Outputs and sin/SAW_OUT_S: R52.2; also elsewhere on the board
/Outputs and sin/TRIANGLE_OUT_S: U7.10 (+); also elsewhere on the board
GND1: C16.2, C17.1, R43.2, R48.2, R49.2, R54.2, R55.2, R59.2, R60.2, R61.2, RV12.1; also elsewhere on the board
unnamed: C18.2, R57.1, R60.1, R63.2, U7.2 (-)
unnamed: C19.1, R64.1, R67.2, U7.7
unnamed: C19.2, R58.1, R61.1, R64.2, U7.6 (-)
unnamed: Q1.1 (E), R45.2, RV11.1
unnamed: Q1.2 (B), R43.1, RV10.1
unnamed: Q1.3 (C), R44.2, R50.2, U7.13 (-)
unnamed: Q2.1 (E), R45.1, RV11.3
unnamed: Q2.2 (B), R48.1
unnamed: Q2.3 (C), R46.2, R49.1, U7.12 (+)
unnamed: R42.1, RV10.2, RV10.3
unnamed: R47.2, RV11.2
unnamed: R50.1, R51.2, U7.14
unnamed: R52.1, R54.1, U7.3 (+)
unnamed: R53.1, R55.1, U7.5 (+)
unnamed: R56.1, R59.1, R62.2, U7.9 (-)
PULSE: R67.1; also elsewhere on the board
SAW: R66.1; also elsewhere on the board
TRI: R65.1; also elsewhere on the board
TRI_RAW: R42.2, R62.1, R65.2, U7.8

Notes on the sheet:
OUTPUT CONDITIONING
Sine amplitude
Kassutronics used 100k feedback resistors and similarly large values for voltage divider resistors. AS3340 datasheet calls for a 51k pulldown on pin 4, so I reduced the voltage divider resistances by a factor ~ (51k/(180k+100k)). Op amp resistances were reduced by a factor of 10. Then stabilization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
SINE SHAPING
Sine symmetry
Sine round

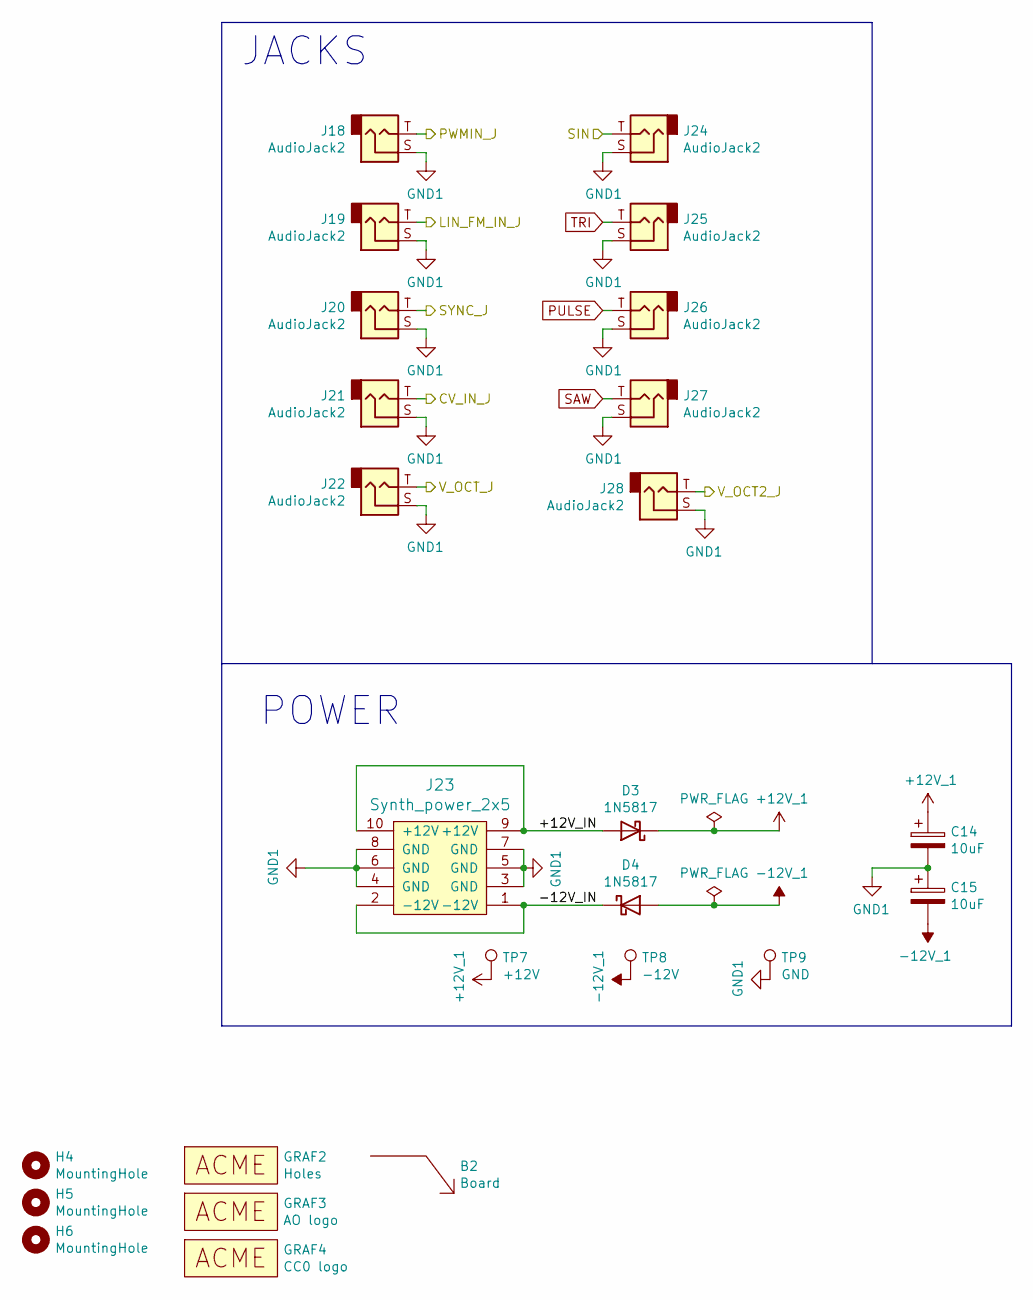
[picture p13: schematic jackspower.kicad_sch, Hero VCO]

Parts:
B2: Board; Board_Marker
C14, C15: 10uF; CP_Radial_D6.3mm_P2.50mm
D3, D4: 1N5817; D_DO-41_SOD81_P10.16mm_Horizontal
GRAF2: Holes; herovco_panel_holes
GRAF3: AO logo; analogoutput
GRAF4: CC0 logo; CC0_logo
H4, H5, H6: MountingHole; MountingHole_3.2mm_M3
J18, J19, J20, J21, J22, J24, J25, J26, J27, J28: AudioJack2; Jack_6.35mm_PJ_629HAN_slots
J23: Synth_power_2x5; Power_Header
TP7: +12V; TestPoint_THTPad_D1.5mm_Drill0.7mm
TP8: -12V; TestPoint_THTPad_D1.5mm_Drill0.7mm
TP9: GND; TestPoint_THTPad_1.5x1.5mm_Drill0.7mm

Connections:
+12V_1: C14.1, D3.1 (K), TP7.1; also elsewhere on the board
-12V_1: C15.2, D4.2 (A), TP8.1; also elsewhere on the board
/Jacks, power, etc/+12V_IN: D3.2 (A), J23.9 (+12V), J23.10 (+12V)
/Jacks, power, etc/-12V_IN: D4.1 (K), J23.1 (-12V), J23.2 (-12V)
/Jacks, power, etc/CV_IN_J: J21.T; also elsewhere on the board
/Jacks, power, etc/LIN_FM_IN_J: J19.T; also elsewhere on the board
/Jacks, power, etc/PWMIN_J: J18.T; also elsewhere on the board
/Jacks, power, etc/SIN: J24.T; also elsewhere on the board
/Jacks, power, etc/SYNC_J: J20.T; also elsewhere on the board
/Jacks, power, etc/V_OCT2_J: J28.T; also elsewhere on the board
/Jacks, power, etc/V_OCT_J: J22.T; also elsewhere on the board
GND1: C14.2, C15.1, J18.S, J19.S, J20.S, J21.S, J22.S, J23.3 (GND), J23.4 (GND), J23.5 (GND), J23.6 (GND), J23.7 (GND), J23.8 (GND), J24.S, J25.S, J26.S, J27.S, J28.S, TP9.1; also elsewhere on the board
PULSE: J26.T; also elsewhere on the board
SAW: J27.T; also elsewhere on the board
TRI: J25.T; also elsewhere on the board

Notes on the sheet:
POWER
JACKS

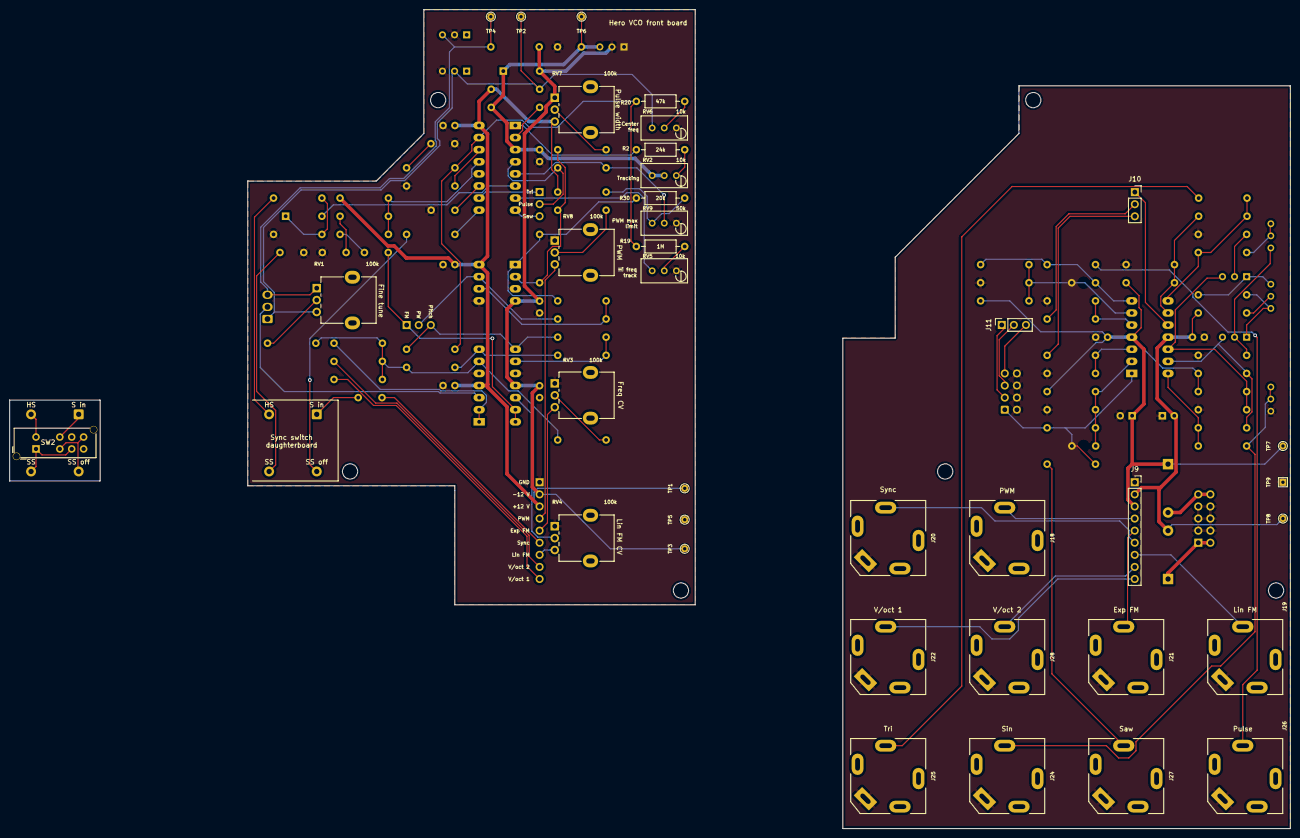
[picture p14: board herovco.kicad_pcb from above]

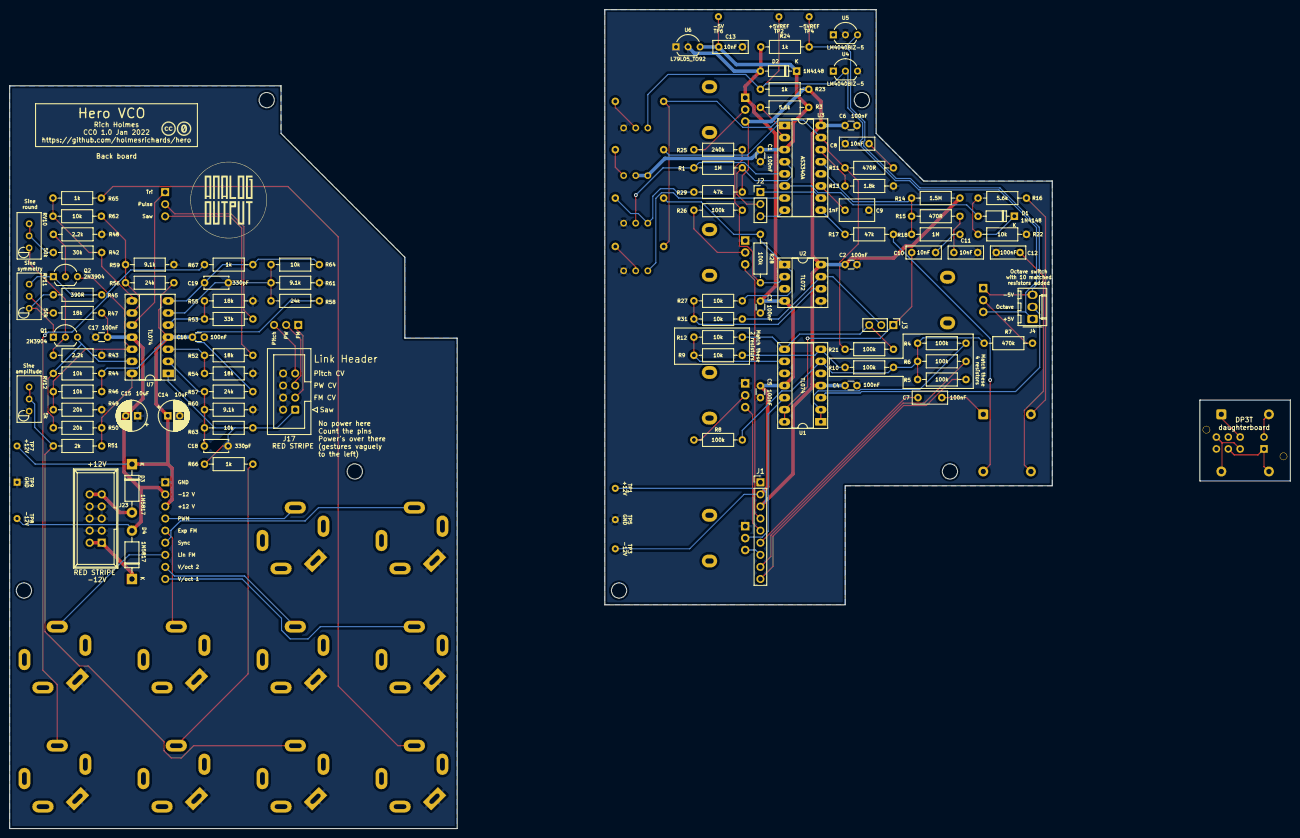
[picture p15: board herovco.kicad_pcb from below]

Board: 2 copper layers, 269.0 x 172.0 mm, 151 parts (96 on the bottom side), 95 nets.

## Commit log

2021-05-01 Initial version
    [1222 LMNC VCO .sch, 3340breadboard.kicad_pcb, 3340breadboard.sch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]
2021-05-07 Update README, some schem/pcb adjustments
    [3340breadboard.sch, 3340vco.sch]
2021-05-30 Catch up various updates
    [3340vco.sch, jackspower.sch, outputs.sch]
2021-09-30 Add link, other schem tweaks
    [3340vco.sch, jackspower.sch, outputs.sch]
2021-09-30 Link corrections
    [3340vco.sch, jackspower.sch, outputs.sch]
2021-10-01 Redesign PWM section for good link setup
    [3340vco.sch, jackspower.sch, outputs.sch]
2021-10-02 Some schematics tweaks, schem PDF
    [3340vco.sch, outputs.sch]
2021-10-02 More schematics tweaks
    [3340vco.sch]
2021-10-02 sch and README tweaks, BOM
    [3340vco.sch, jackspower.sch, outputs.sch]
2021-10-03 Fix brain dead op amp topology, and improve voltage reference and its use
    [3340vco.sch, jackspower.sch, outputs.sch]
2021-10-03 Put that resistor back
    [jackspower.sch]
2021-10-03 Preliminary board division and layout
    [3340vco.kicad_pcb, 3340vco.sch, jackspower.sch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]
2021-10-04 More layout work
    [3340vco.kicad_pcb, 3340vco.sch, jackspower.sch]
2021-10-05 Replace tri to sine, more layout
    [3340vco.kicad_pcb, 3340vco.sch, jackspower.sch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]
2021-10-08 Fix label
    [3340vco.kicad_pcb, outputs.sch]
2021-10-26 Update annotations
    [3340vco.sch]
2021-10-27 Revise power ports
    [3340vco.kicad_pcb, 3340vco.sch, jackspower.sch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]
2021-10-27 Revise headers, silkscreen
    [3340vco.kicad_pcb, 3340vco.sch, jackspower.sch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]
2021-10-27 Rename and break PCBs out to separate projects
    [3340vco.kicad_pcb, herovco_back.kicad_pcb, herovco_back.sch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]
2021-10-28 BOMs, resistor symbol normalization
    [herovco_back.sch, herovco_front.sch]
2021-10-30 Revised output stage values
    [herovco_back.sch]
2021-10-30 Revise annotation
    [herovco_front.sch]
2021-11-01 Change regulator output cap and rearrange
    [herovco_front.kicad_pcb, herovco_front.sch]
2021-11-01 First routing
    [herovco_back.kicad_pcb, herovco_front.kicad_pcb, herovco_front.sch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]
2021-11-01 Panel in KiCad
    [herovco_front.kicad_pcb, herovco_front.sch, herovco_panel.kicad_pcb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]
2021-11-02 Rear panel labels
    [herovco_panel.kicad_pcb]
2021-11-02 PCB labels
    [herovco_back.kicad_pcb, herovco_front.kicad_pcb, herovco_front.sch]
2021-11-17 Change of plan, both boards in one project (but never again)
    [herovco.kicad_pcb, herovco.sch, herovco_back.kicad_pcb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]
2021-11-18 Test points
    [herovco.kicad_pcb, herovco_front.sch, jackspower.sch]
2021-11-25 rm cruft
    [herovco_frontx.sch]
2021-12-10 Version 6 (PCB)
    [herovco.kicad_pcb, herovco.kicad_sch, herovco.sch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]
2021-12-10 Change pot symbols and fix orientation, other small tweaks
    [herovco.kicad_sch, herovco_back.kicad_sch, herovco_front.kicad_sch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]
2021-12-22 Pre-breadboard updates
    [herovco.kicad_pcb, herovco.kicad_sch, herovco_back.kicad_sch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]
2022-01-17 rm Zener, change adj ref to fixed and modify octave switch and fine tune accordingly
    [herovco.kicad_pcb, herovco.kicad_sch, herovco_front.kicad_sch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]
2022-01-17 rm Zener, change adj ref to fixed, cont'd
    [herovco.kicad_pcb, herovco.kicad_sch, herovco_front.kicad_sch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]
2022-01-18 Panel updates; reannotate; correct PCB errors
    [herovco.kicad_pcb, herovco.kicad_sch, herovco_back.kicad_sch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]
2022-01-18 Sync input revision
    [herovco.kicad_sch, herovco_back.kicad_sch, herovco_front.kicad_sch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]
2022-01-19 Big panel and PCB revisions
    [herovco.kicad_pcb, herovco.kicad_sch, herovco_front.kicad_sch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]
2022-01-19 Sch cleanup, switch footprint
    [herovco.kicad_pcb, herovco.kicad_sch, herovco_back.kicad_sch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]
2022-01-19 rm superfluous header pin
    [herovco.kicad_pcb, herovco.kicad_sch]
2022-01-21 Different sync switch, other tweaks
    [herovco.kicad_pcb, herovco.kicad_sch, herovco_front.kicad_sch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]
2022-01-26 Sine trimmers to back board, misc accumulated tweaks
    [herovco.kicad_pcb, herovco.kicad_sch, herovco_back.kicad_sch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]
2022-01-29 Schematics tweaks, silk and fab cleanup, layout PDFs, panel revisions
    [herovco.kicad_pcb, herovco.kicad_sch, herovco_back.kicad_sch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]
2022-01-29 Panel revision, Gerbers
    [herovco_back-CmtUser.gbr, herovco_back-CuBottom.gbl, herovco_back-CuTop.gtl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]
2022-01-30 Fix switch PCB
    [herovco.kicad_pcb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]
2022-01-30 100k in octave switch; rotary footprint; note stuff to fix
    [herovco.kicad_pcb, herovco.kicad_sch, octave.kicad_sch]
2022-02-01 schem tweaks
    [herovco.kicad_pcb, herovco.kicad_sch, herovco_back.kicad_sch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]
2022-03-06 Initial BOM; DNF the test points; README typo
    [herovco.kicad_sch, herovco_front.kicad_sch, jackspower.kicad_sch]
2022-03-06 Convert jack footprints to slotted; clean up silkscreen; add silkscreen notes to match resistors
    [herovco.kicad_pcb, herovco.kicad_sch, jackspower.kicad_sch]
2022-03-06 Correct slide switch footprint; use TO-92 wide for regulator
    [herovco.kicad_pcb, herovco.kicad_sch, herovco_front.kicad_sch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]
2022-03-06 5 mm pitch for 330 pF
    [herovco.kicad_pcb, herovco.kicad_sch, herovco_back.kicad_sch]
2022-03-06 Resistors between trimmers to other side of front board
    [herovco.kicad_pcb]
2022-03-07 New schematic PDF
2022-03-08 10k resistors in octave switch
    [herovco.kicad_sch, octave.kicad_sch]
2022-03-08 10k resistors in octave switch (build doc)
2022-03-09 Use uninverted PW CV
    [herovco.kicad_pcb, herovco_front.kicad_sch]
2022-03-09 Revert "Use uninverted PW CV"
    This reverts commit afeb33e5ee15cb89f0e577c33928166723912ed3.
    [herovco.kicad_pcb, herovco_front.kicad_sch]
2022-03-09 Note on PW CV
    [herovco_front.kicad_sch]
2022-06-19 Post prototype updates
    [herovco.kicad_sch, herovco_back.kicad_sch, herovco_front.kicad_sch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]
2022-06-19 Libraries, redo gerbers
    [herovco_back.kicad_pcb, herovco_front.kicad_pcb, herovco_switch.kicad_pcb]
2022-06-24 20k trimmers to 10k
    [herovco.kicad_pcb, herovco.kicad_sch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]
